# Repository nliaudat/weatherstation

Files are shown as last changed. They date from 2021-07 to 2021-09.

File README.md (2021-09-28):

# Weatherstation
A 3d printed diy weather station with anemometer and direction vane. Others sensors will be available soon...

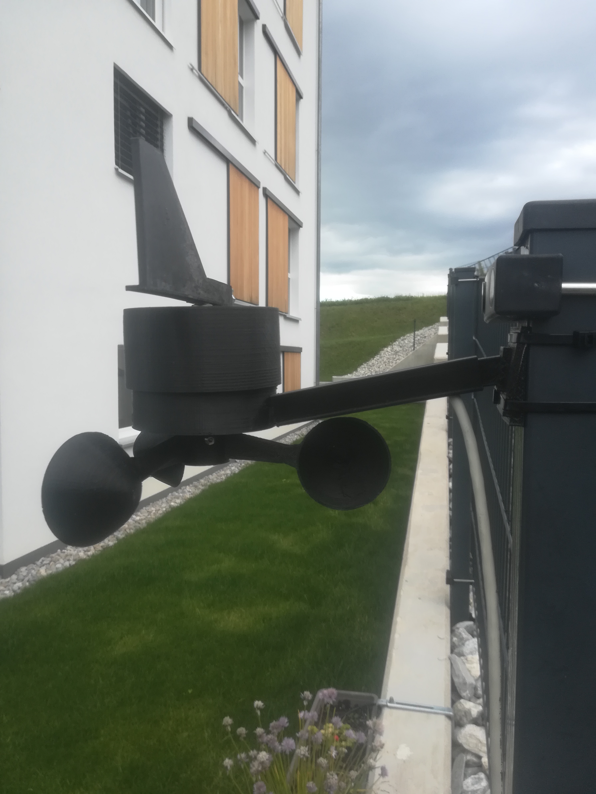
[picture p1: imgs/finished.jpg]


## Abstract

Yet another weather station, but that one use a magnetometer for the direction vane and a rotary encoder with an IR optocoupler for the anemometer.
It runs with an ESP board and [Esphome software](https://esphome.io/)

## Direction Vane

The direction vane use an 1.2$ HMC5883L or QMC5883L Magnetometer and a magnet. The simplest is the best !

I've made a [precise calibration script](https://github.com/nliaudat/magnetometer_calibration) if needed to correct hard & soft iron effects with ellipsoid fitting.

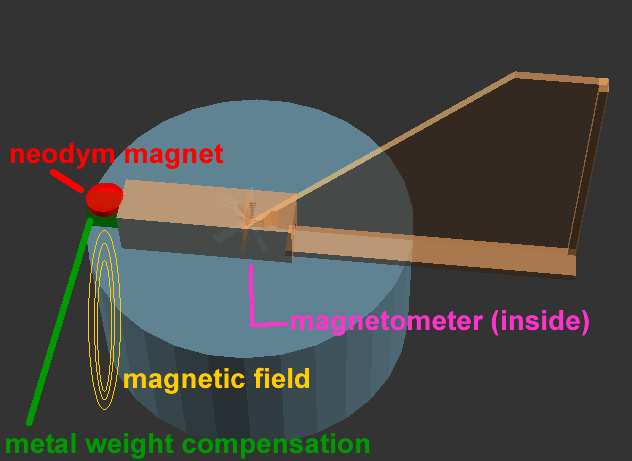
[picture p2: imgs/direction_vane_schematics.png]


## Anemometer

The anemometer use a rotary encoder with an 0.6$ IR optocoupler. 

The openscad script (all parametric) output all needed informations to calculate the wind speed except the correction/friction factor which depends on your ball bearing. (mine is 5 and it's a good starting point for futher calibration)

```
[Wind speed in m/s] = 2PI * [anemometer mid cup to axle lenght in m]  * [revolution per seconds]  * [unknown correction factor]
anemometer mid cup to axle lenght = 72.5 mm => 72.5/1000 = 0.0725 m for R
rotary encoder pulse per revolution : 36
revolution per seconds = pulses /36 /60
S = 2PI * 0.0725 * pulses /36 /60 = 0.00021089395
Speed m/s => Km/h : *3.6 => 0.00075921822
[unknown correction factor or friction] : mine is ~5 => 0.00075921822 *5 = 0.0037960911 

You must paste that value in "pulse_meter" section of esphome.yaml
    filters:
      - multiply: 0.0037960911 
```

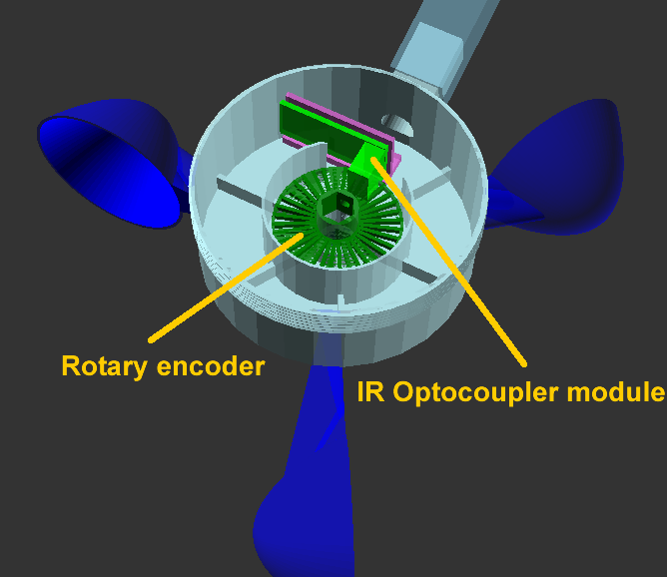
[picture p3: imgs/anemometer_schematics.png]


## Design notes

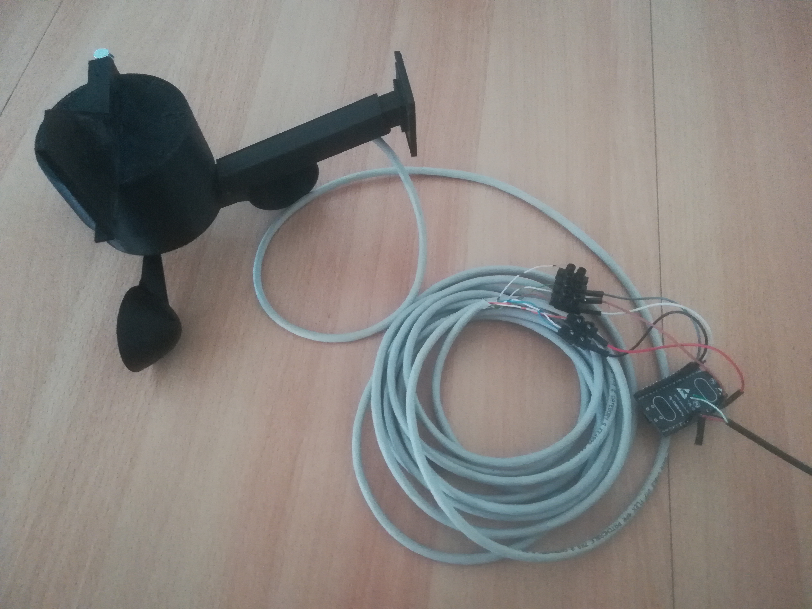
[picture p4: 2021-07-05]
imgs/2021-06-18 19.50.15.jpg

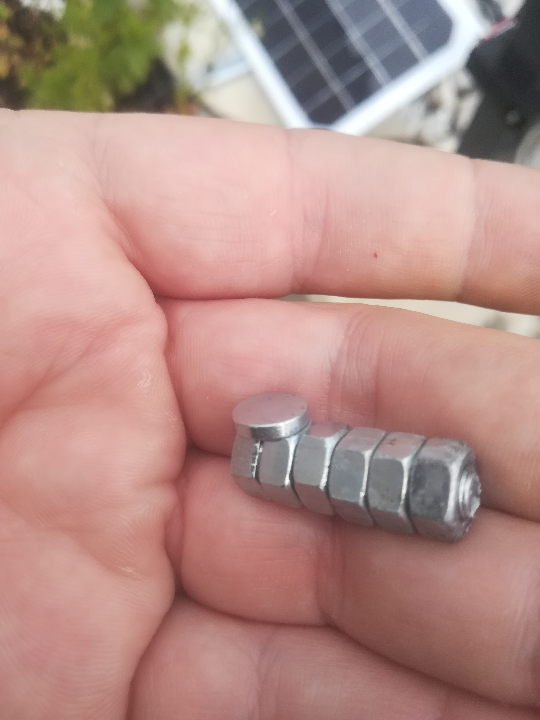
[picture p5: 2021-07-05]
imgs/vane_weight_compensation_and_magnet.jpg

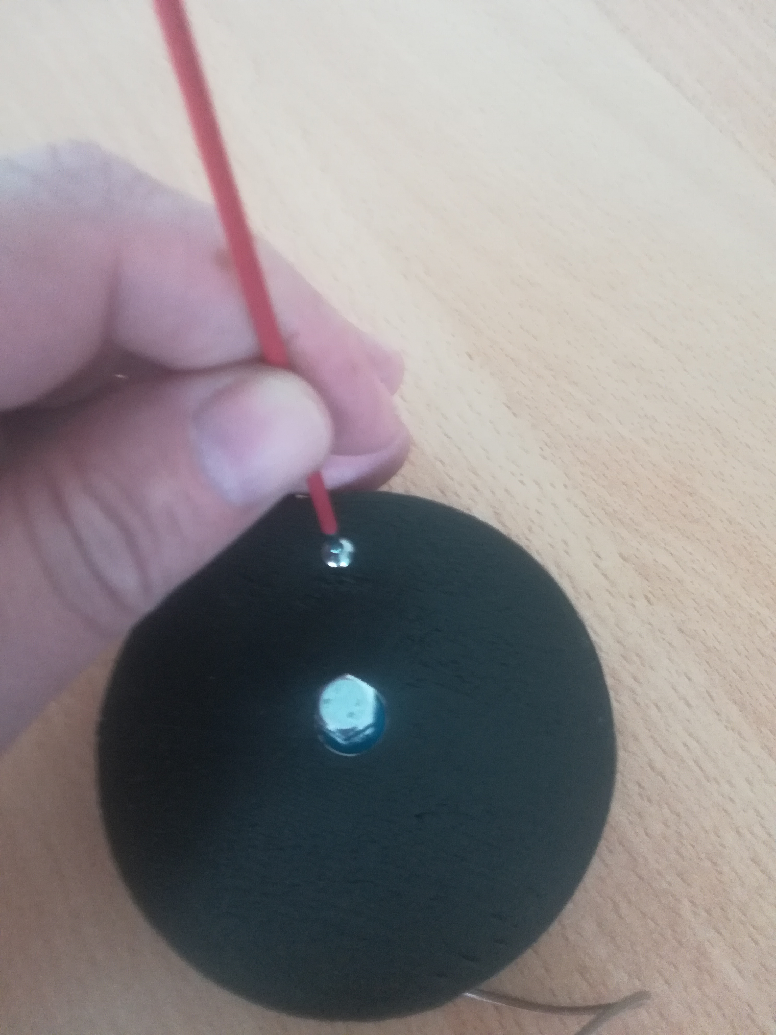
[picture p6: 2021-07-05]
imgs/2021-06-18 13.42.44.jpg

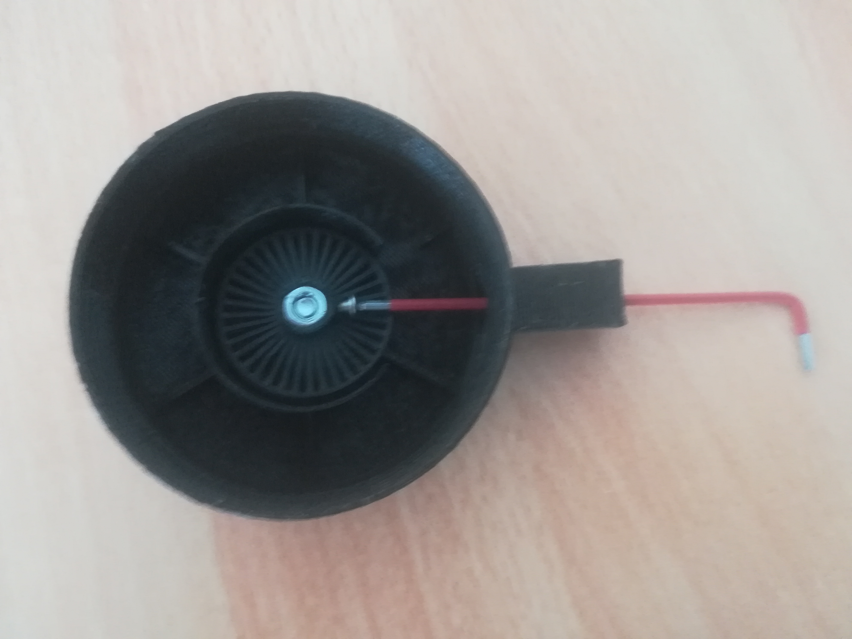
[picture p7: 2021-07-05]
imgs/2021-06-18 13.35.45.jpg

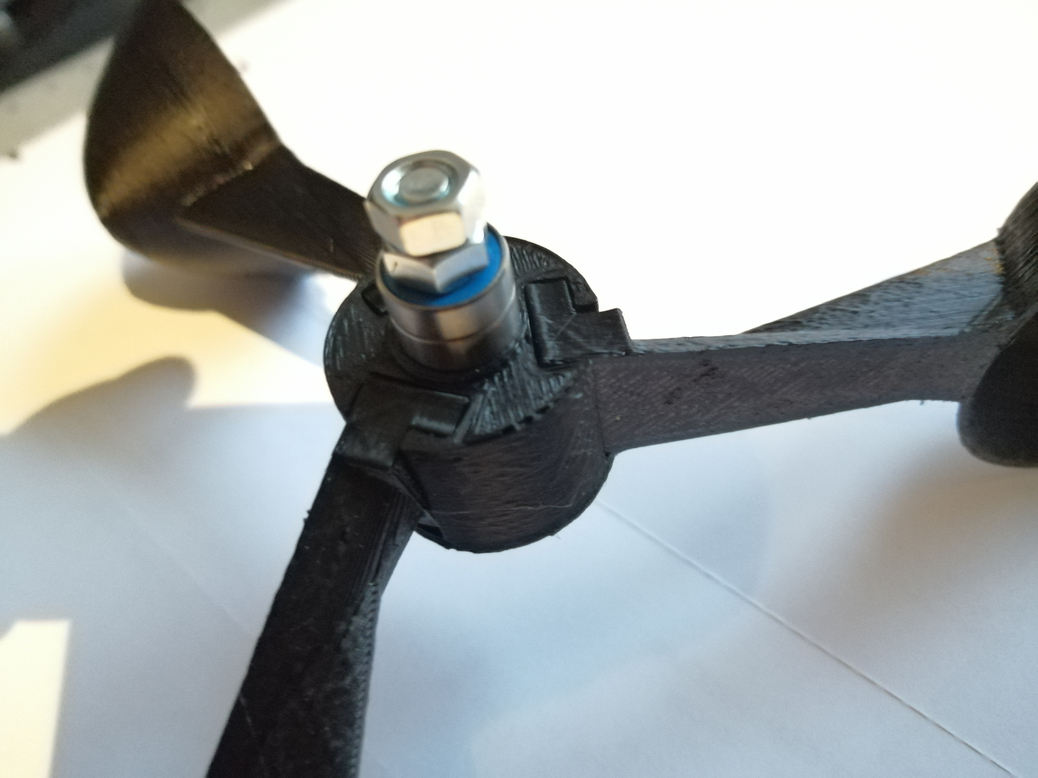
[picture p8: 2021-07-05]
imgs/2021-05-05 20.09.54.jpg

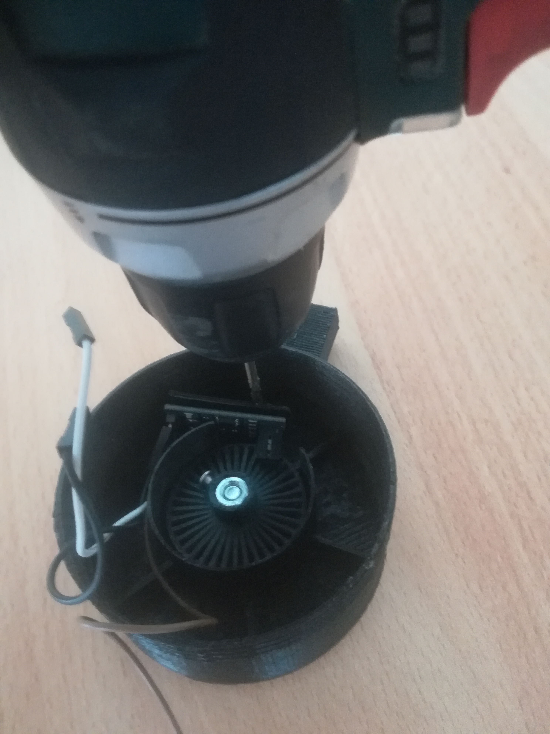
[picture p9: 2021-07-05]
imgs/drill_2.5mm.jpg

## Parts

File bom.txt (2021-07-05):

###################
#Bill of materials 
###################

IR opto sensor : 0.58$ (https://fr.aliexpress.com/item/32850602744.html?spm=a2g0o.productlist.0.0.1e87321dwf0sa0)
magnetometer HMC5883L : 1.2$ (https://fr.aliexpress.com/item/32787753257.html?spm=a2g0s.9042311.0.0.66f36c37ynHEjJ)
Optional : Rain sensor module : 0.35$ https://fr.aliexpress.com/item/1005001944025255.html?spm=a2g0s.9042311.0.0.350f6c37agik5L

##########
#Screws : 
##########

2 Axles : 
2x M5x20 hex screw
4x M5 hex bolt
2x M5 nylstop hex bolt
4x M5 ball bearing (ID 5mm), you can customize in openscad. I used MR115RS 5x11x4mm

Van weight compensation and magnetic field : 
1x M5x20 hex screw
5x M5 hex bolt
1x neodym magnet

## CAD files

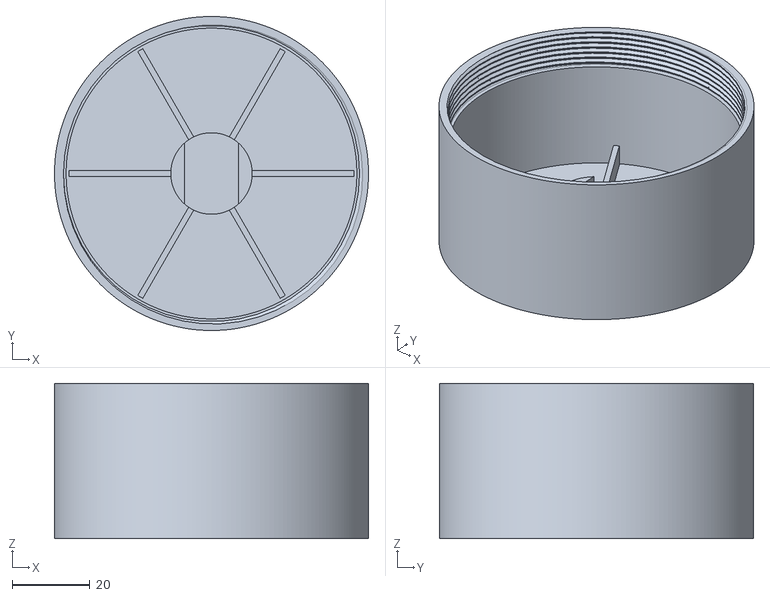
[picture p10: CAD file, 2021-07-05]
3D_print/weather_station_top.stl
81.0 x 81.0 x 40.0

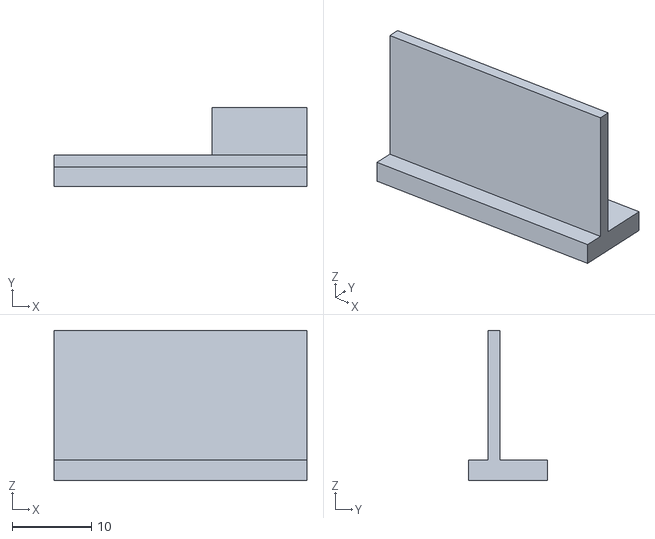
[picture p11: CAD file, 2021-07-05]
3D_print/optical_sensor_support.stl
32.0 x 10.0 x 19.0

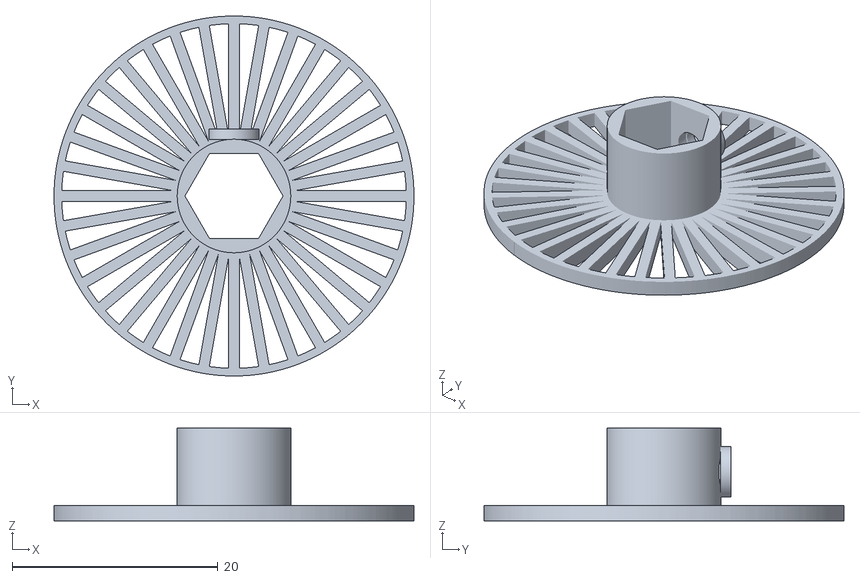
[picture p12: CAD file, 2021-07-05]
3D_print/anemometer_rotary_encoders.stl
35.0 x 35.0 x 9.00

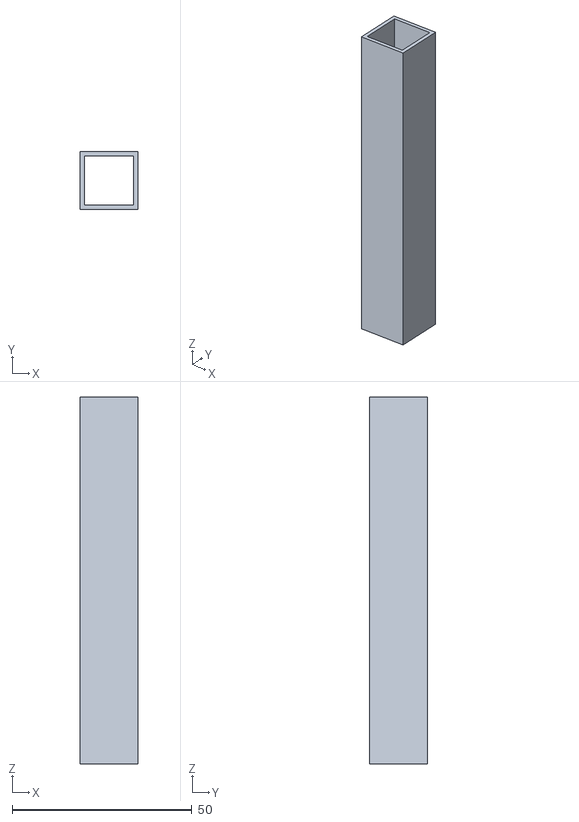
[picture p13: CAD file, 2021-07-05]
3D_print/outer_pipe.stl
16.0 x 16.0 x 102.0

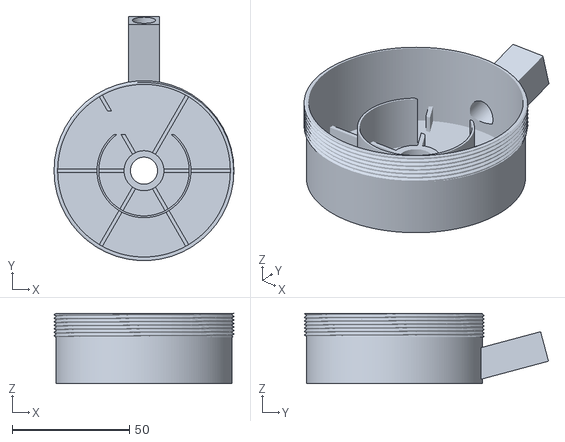
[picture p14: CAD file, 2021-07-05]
3D_print/weather_station_bottom.stl
76.7 x 103.9 x 30.0

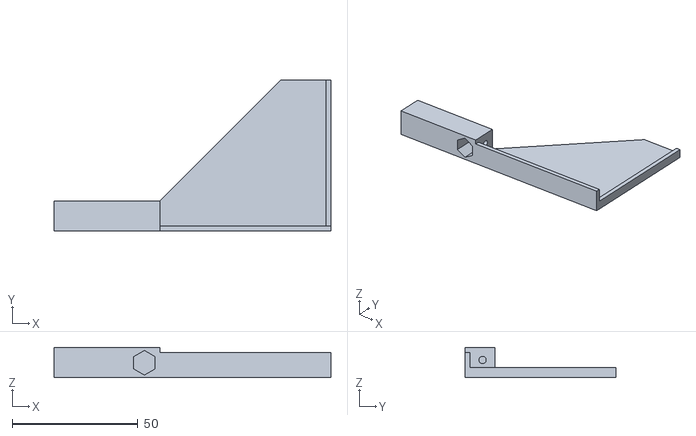
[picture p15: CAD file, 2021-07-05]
3D_print/direction_vane.stl
110.0 x 60.0 x 12.0

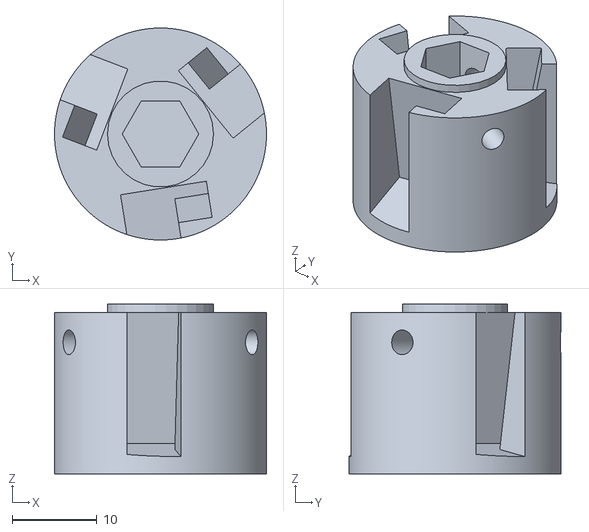
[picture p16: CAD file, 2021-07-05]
3D_print/anemometer_axle.stl
25.0 x 25.0 x 20.0

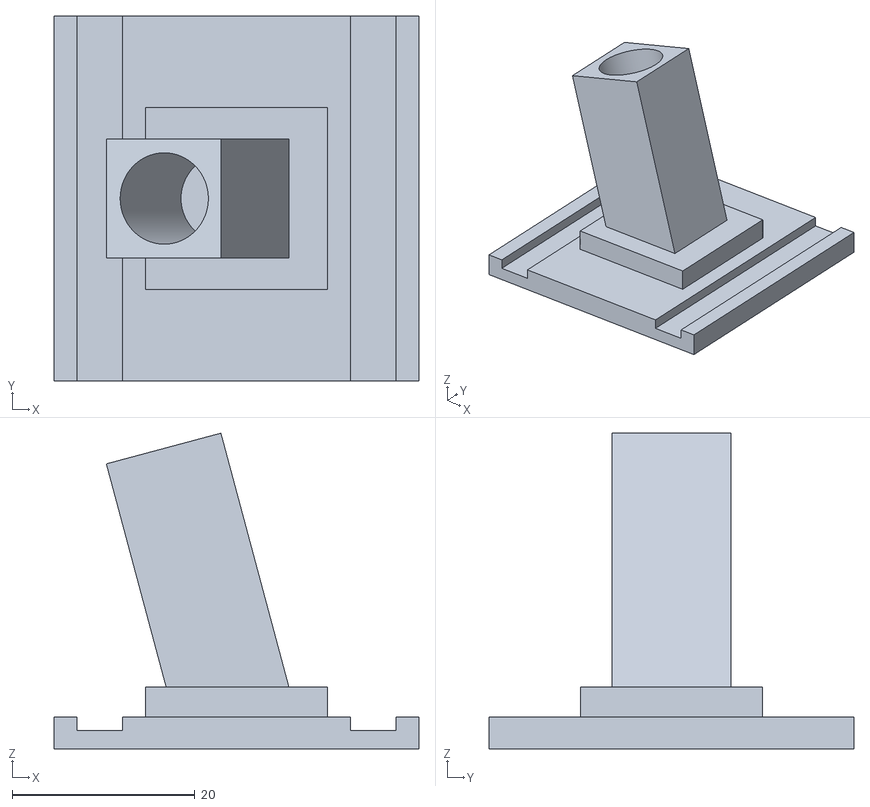
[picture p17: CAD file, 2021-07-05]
3D_print/pipe_hang.stl
40.0 x 40.0 x 34.6

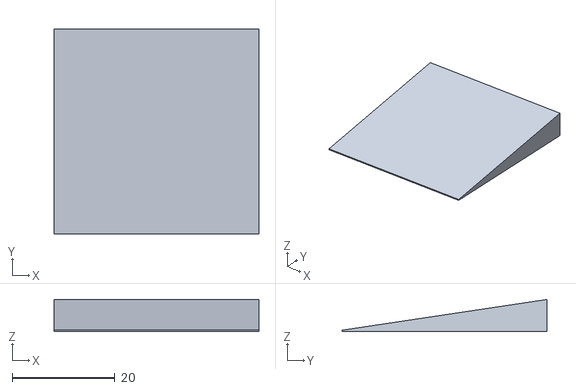
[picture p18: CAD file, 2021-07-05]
3D_print/pipe_hang_adjustement.stl
40.0 x 40.0 x 6.25

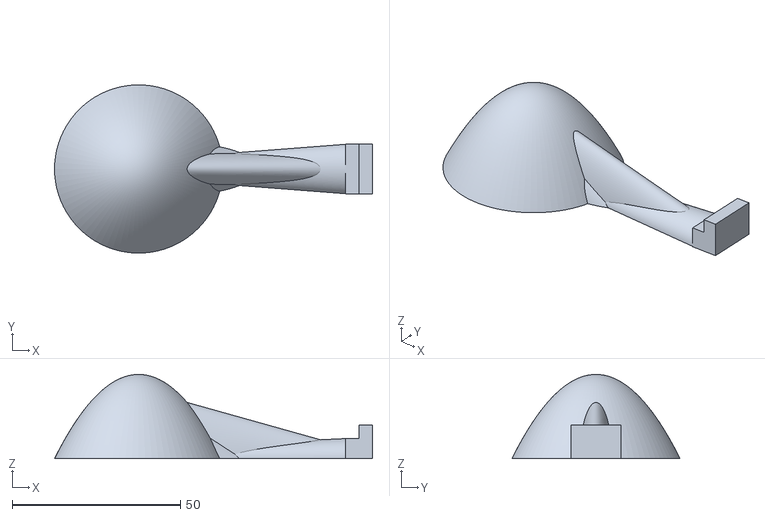
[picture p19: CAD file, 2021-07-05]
3D_print/anemometer_cup.stl
94.5 x 50.0 x 25.0

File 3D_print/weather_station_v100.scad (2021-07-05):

/*
#####################
#  print settings : #
#####################

anemometer cups : 94.5x50x25mm(6.6g pla) => 
====================
no support
infill density : 30%
infill pattern : cubic subdivision

anemometer axle : 25x25x20mm (4.1g pla)
====================
no support
infill density : 30%
infill pattern : cubic subdivision

anemometer_rotary_encoder : 35x35x8mm (2g pla)
====================
no support


direction vane : 110x60x12mm (12g pla)
====================
no support

body bottom : 95x77x30mm (21g pla)
====================
no support or [support, no tower] depend on the printer


body top : 81x81x40mm (35g pla)
====================
no support
raft (optional)

outer pipe : 16x16x102mm (9g pla)
====================
no support
combining mode : not in skin


####Anemometer calculus : 

https://fr.wikipedia.org/wiki/An%C3%A9mom%C3%A8tre#An%C3%A9mom%C3%A8tre_%C3%A0_coupelles_(dit_de_Robinson)


[Wind speed in m/s] = 2PI * [anemometer mid cup to axle lenght in m]  * [revolution per seconds]  * [unknown correction factor]

anemometer mid cup to axle lenght = 72.5 mm => 72.5/1000 = 0.0725 m for R

rotary encoder pulse per revolution : 36

revolution per seconds = pulses /36 /60
S = 2PI * 0.0725 * pulses /36 /60 = 0.00021089395

Speed m/s => Km/h : *3.6 => 0.00075921822

[unknown correction factor or friction] = ~5 => 0.00075921822 *5

*/

// Use thread library from http://dkprojects.net/openscad-threads/
include <threads.scad>;

//###############
//#### Parametric 

/* [anemometer cup] */
number_of_cups=3;//number of cup
cup_diameter=50; // [10:5:100]
cup_height=25; // [10:5:50]
cup_tickness=1.00; //[0.75:0.25:3.5]

arm_tickness=3.5; //[1.25:0.25:5.5]
arm_length=50; // [30:5:150]
arm_scale_height=5; //[1:1:12]
arm_scale_width=1.5; //[0.25:0.25:5]
arm_cylinder_length=5; // [2:1:10]
arm_screw_diam=2.9; //[1:1:5]

/* [anemometer axle] */
anemometer_axle_diameter=25; // [10:1:35]
anemometer_axle_height=20; // [10:1:30]
anemometer_axle_angle=10; // [0:1:45]

//anemometer_axle_joint_scale=1.075; // [0.9:0.0025:1.25]
//1.05 too thin
//1.15 too large

/* [anemometer rotary encoders] */
anemometer_rotary_encoder_pulses_per_revolution=36;// [2:2:36]
anemometer_rotary_encoder_height=1.5;// [0.5:0.5:3]
anemometer_rotary_encoder_diam=35;// [10:5:70]



/* [weather_station case] */

weather_station_diam=75; // [50:5:100]
weather_station_tickness=1.50; //[0.50:0.25:5.5]
weather_station_bottom_height=30; // [15:5:60]
weather_station_top_height=40; // [15:5:60]
ball_bearing_diam=11; // [10:1:30]
ball_bearing_height=8; // [6:1:10]
mounting_pipe_inner_diam=13;//[10:1:20]
mounting_pipe_lenght=100; //[80:10:180]
mounting_pipe_support_lenght=30; //[30:10:50]
mounting_pipe_angle=-15;
//mounting_pipe_outer_diam=16;
//hang_pipe_lenght=80; //[70:10:150]

/* [vane] */
vane_blade_lenght=80; //[30:1:150]
vane_blade_height=60; //[30:1:150]
vane_blade_tickness=2; //[1:1:5]




/* [rendering] */

render="all"; //[anemometer_cup,anemometer_axle,anemometer_rotary_encoders,weather_station_bottom,weather_station_top,direction_vane,optical_sensor_support,pipe_hang,outer_pipe,all,bottom_only,top_only,pipe_hang_adjustement]

$fn=200;
debug=false;

/* [Hidden] */
pla_retraction=0.5;
screw_length=20;
screw_diam=5;
//https://itafasteners.com/products-bolts-hex-head-anchor-bolts.php
screw_bolt_tolerance=0.25;
screw_bolt_diam=8.79+screw_bolt_tolerance;//+pla_retraction;
screw_bolt_height=3.5;
threads_pitch = 1.5;//weather_station_tickness/2;//1.5;

//calculus : 

anemometer_axis_dist=(cup_diameter/2+arm_length+anemometer_axle_diameter/2-15)*cos(anemometer_axle_angle*PI/180);//mm
anemometer_max_rps=50*1/(anemometer_axis_dist/1000*PI);//rotation per second at 50m/s = 180km/h
anemometer_cup_weight=6.6;



echo("anemometer mid cup to axle lenght=",anemometer_axis_dist ,"mm");

echo("anemometer max rps at 50m/s(180km/h)=",
    anemometer_max_rps*60, "rpm or", anemometer_max_rps, "r/sec" );
    
    
echo("max encoder Hz at 50m/s=",
    anemometer_max_rps *anemometer_rotary_encoder_pulses_per_revolution, "Hz (must be < 76923Hz = 13µs esp32 limit)" );

echo("Centrifugal force for a ",anemometer_cup_weight,"g cup at 50m/s=",
    (anemometer_cup_weight/1000 *(50^2))/(anemometer_axis_dist/1000), " N (must be < 250 N PLA traction resitance)" );//FC = mv²/R.
    
echo("Anemometer wind speed factor ([Wind speed in m/s] = 2PI * [anemometer mid cup to axle lenght in m] /2 * [revolution per seconds] ): ",2*PI* anemometer_axis_dist/1000 /anemometer_rotary_encoder_pulses_per_revolution /60 );



if (render=="all") {
   
    $fn=30;
    
    //cups axle
    translate([0,0,-anemometer_axle_height])anemometer_axle();
    
    //cups
    for ( i = [0 : number_of_cups-1] )
    {
    rotate( i * 360 / number_of_cups, [0, 0, 1])
    translate([-arm_length-anemometer_axle_diameter,anemometer_axle_diameter,-anemometer_axle_height])
        rotate([90,-anemometer_axle_angle,0])
   anemometer_cup(); 
    }
    
    
    //body bottom
    color( "PowderBlue", 0.8 )
   weather_station_bottom();
    //encoder
    color( "green", 0.8 )
    //translate([0,0,ball_bearing_height+2*screw_bolt_height+3])
    //rotate([180,0,0])
    translate([0,0,ball_bearing_height+weather_station_tickness])
    anemometer_rotary_encoders();
    //optical sensor
    color( "Lime", 0.8 )
    //translate([-10,anemometer_rotary_encoder_diam/2+2,ball_bearing_height+2*screw_bolt_height+3])
    translate([-12,anemometer_rotary_encoder_diam/2+3,ball_bearing_height+2])rotate([180,0,0])
    pcb_optical_sensor();
    
    //esp32
    //translate([0,0,ball_bearing_height*2+2*screw_bolt_height+15])color( "Gold", 0.8 )pcb_esp32();
    
    //body top
    color( "SkyBlue", 0.8 )
    translate([0,0,weather_station_bottom_height+weather_station_top_height-10])
    rotate([180,0,0])
    weather_station_top();
    
    
    //direction_vane
    color( "SandyBrown", 0.8 )
    translate([0,0,weather_station_bottom_height+weather_station_top_height-10])
    rotate([90,0,0])
    direction_vane();
    
        //outer_pipe
    color( "SkyBlue", 0.5 )
    rotate([0,0,90])translate([weather_station_diam/2+mounting_pipe_support_lenght/2-3,0,weather_station_bottom_height/2-3])rotate([0,90,0])rotate([0,mounting_pipe_angle,0])outer_pipe();
    
    //pipe_hang
    color( "Orchid", 0.8 )
    rotate([0,0,90])translate([weather_station_diam/2+mounting_pipe_support_lenght*4,0,weather_station_bottom_height/2-4+mounting_pipe_support_lenght])rotate([0,270,0])pipe_hang();
    
}

if (render=="bottom_only") {
   
    $fn=30;
    
    //cups axle
    translate([0,0,-anemometer_axle_height])anemometer_axle();
    
    //cups
    for ( i = [0 : number_of_cups-1] )
    {
    rotate( i * 360 / number_of_cups, [0, 0, 1])
    translate([-arm_length-anemometer_axle_diameter,anemometer_axle_diameter,-anemometer_axle_height])
        rotate([90,-anemometer_axle_angle,0])
   anemometer_cup(); 
    }
    
    
    //body bottom
    color( "PowderBlue", 0.8 )
   weather_station_bottom();
    //encoder
    color( "green", 0.8 )
    //translate([0,0,ball_bearing_height+2*screw_bolt_height+3])
    //rotate([180,0,0])
    translate([0,0,ball_bearing_height+weather_station_tickness])
    anemometer_rotary_encoders();
    //optical sensor
    color( "Lime", 0.8 )
    //translate([-10,anemometer_rotary_encoder_diam/2+2,ball_bearing_height+2*screw_bolt_height+3])
    translate([-12,anemometer_rotary_encoder_diam/2+3,ball_bearing_height+7])rotate([180,0,0])
    pcb_optical_sensor();
    
    
    color( "Orchid", 0.8 )
    translate([-27,anemometer_rotary_encoder_diam/2+4,ball_bearing_height-3])
    optical_sensor_support();
    
    //esp32
    //translate([0,0,ball_bearing_height*2+2*screw_bolt_height+15])color( "Gold", 0.8 )pcb_esp32();
    
    //outer_pipe
    color( "SkyBlue", 0.5 )
    rotate([0,0,90])translate([weather_station_diam/2+mounting_pipe_support_lenght/2-3,0,weather_station_bottom_height/2-3])rotate([0,90,0])rotate([0,mounting_pipe_angle,0])outer_pipe();
    
    //pipe_hang
    color( "Orchid", 0.8 )
    rotate([0,0,90])translate([weather_station_diam/2+mounting_pipe_support_lenght*4,0,weather_station_bottom_height/2-4+mounting_pipe_support_lenght])rotate([0,270,0])pipe_hang();
    
    
}
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

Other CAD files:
3D_print/threads.scad

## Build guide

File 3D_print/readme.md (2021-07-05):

The case could contains the ESP board, but you must enlarge a bit the bottom and top height to fit cables properly.

All the printing do not need supports

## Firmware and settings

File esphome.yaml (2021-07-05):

# for flashing : press boot button for 2-3 seconds before the serial connection initialize
# After OTA update, the EN (reset) button must be pressed to run firmware
# do not use gpio12 (MTDI)

substitutions:
  name: weatherstation
  friendly_name: "Weather Station"

esphome:
  name: $name
  platform: ESP32
  board: nodemcu-32s 

wifi:
  networks:
  - ssid: !secret wifi_ssid_1
    hidden: true
    password: !secret wifi_password_1
    priority : 1
  - ssid: !secret wifi_ssid_2
    hidden: true
    password: !secret wifi_password_2
    priority : 2
  - ssid: !secret wifi_ssid_3
    password: !secret wifi_password_3
    priority : 3


    
    # Optional manual IP
  manual_ip:
    static_ip: 192.168.1.138
    gateway: 192.168.1.1
    subnet: 255.255.255.0
    dns1: 192.168.1.1
    dns2: 8.8.8.8

  # Enable fallback hotspot (captive portal) in case wifi connection fails
  ap:
    ssid: "${name} Fallback"
    password: !secret fallback_hotspot_password

captive_portal:


logger:
  level: DEBUG #NONE# ERROR #INFO #DEBUG  #VERBOSE
  logs:
    sensor: WARN
    binary_sensor: WARN
    switch: WARN
    hmc5883l: WARN
    text_sensor: WARN
    pulse_counter: WARN
    pulse_meter: WARN
    adc: WARN


# Enable Home Assistant API
api:

ota:

# sun:
   # latitude: !secret latitude
   # longitude: !secret longitude
   
globals:
  - id: enable_magnetometer_serial_output
    type: bool
    restore_value: no
    initial_value: 'false' 
    
i2c:
   - id: bus_a
     sda: GPIO21
     scl: GPIO22
     scan: False #True only if hmc5883l not detected at address 0x1E
     #frequency: 100kHz (max 400 kHz for hmc5883l)

sensor:      
  - platform: wifi_signal
    name: "${friendly_name} WiFi Signal"

  # - platform: adc
    # pin: VCC
    # name: "ESP8266 chip Voltage"
    
  - platform: adc
    pin: GPIO32 #GPIO32 through GPIO39
    name: "Battery voltage" #input  14V to 0.9V E6 20% tolerance => R1 = 680k, R2 = 47k | Vin/Vout ratio = 15.5 (https://www.random-science-tools.com/electronics/divider.htm)
    attenuation: 0db #1.1V
    filters:
      - multiply: 15.5
      - max:
          window_size: 5
          send_every: 5
          send_first_at: 5
      - calibrate_polynomial:
          degree: 2
          datapoints:    # Map 0.0 (from sensor) to 0.0 (true value)
             - 4.85 -> 7.0
             - 6.15 -> 8.0      
             - 7.5 -> 9.0
             - 8.5 -> 10.0
             - 9.85 -> 11.0
             - 11.0 -> 12.0
             - 12.15 -> 13.0
             - 13.35 -> 14.0
             - 14.5 -> 15.0
    accuracy_decimals: 1
    update_interval: 1s
    
  - platform: uptime
    name: "${friendly_name} Uptime"    
    id: uptime_sensor
    update_interval: 60s
    internal: true
    on_raw_value:
      then:
        - text_sensor.template.publish:
            id: uptime_human
            state: !lambda |-
              int seconds = round(id(uptime_sensor).raw_state);
              int days = seconds / (24 * 3600);
              seconds = seconds % (24 * 3600);
              int hours = seconds / 3600;
              seconds = seconds % 3600;
              int minutes = seconds /  60;
              seconds = seconds % 60;
              return (
                (days ? String(days) + "d " : "") +
                (hours ? String(hours) + "h " : "") +
                (minutes ? String(minutes) + "m " : "") +
                (String(seconds) + "s")
              ).c_str();
              
    #https://esphome.io/components/sensor/hmc5883l.html?highlight=hmc5883
    #I2C connected : SDA (GPIO21) and SCL (GPIO22)
  - platform: hmc5883l
    address: 0x1E
    field_strength_x:
      name: "HMC5883L Field Strength X"
      internal: true
      id: hmc5883l_x   
    field_strength_y:
      name: "HMC5883L Field Strength Y"
      internal: true
      id: hmc5883l_y
    field_strength_z:
      name: "HMC5883L Field Strength Z"
      internal: true
      id: hmc5883l_z
    heading:
      name: "${friendly_name} wind heading"
      id: hmc5883l_heading
      internal: true
      filters:
      - lambda: |-
            if(x < 0){ return x +360;}
            else{return x;}
    oversampling: 8x #1x
    range: 810uT #Supported values are 88µT, 130µT, 190µT, 250µT, 400µT, 470µT, 560µT, 810µT. Default range is ±130µT.
    update_interval: 1s #max 160Hz=6.25 ms but that component cannot be under 1s
    id: meteo_station_HMC5883L_magnetometer
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
